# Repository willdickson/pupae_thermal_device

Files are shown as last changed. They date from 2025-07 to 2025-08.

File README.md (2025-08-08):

## pupae_thermal_device  

A temperature controller for thermal experiments with
Drosophila melanogaster pupea. This device consists of two almuminum plates
separated by a narrow channel in which pupae are placed. Each aluminum plate
has a temperature sensor on the upper surface and sits a Peltier thermoelectric
module.  The temperature of the plates is controlled independently using a
feedback (PID) temperature controller implemented on the an Adafruit Feather
RP2350 in combination with the Adafruit DC Motor Featherwing and Sparkfun's
micro STTS22H temperature sensor. The set-points, plate temperatures and
enabled/disable status are displayed on an Adafruit OLED Featherwing. The three
(A, B, C) buttons on the OLED Fetherwing are used to control the plate set-point temperatures 
and to toggle the controller's enabled/disabled state.

## License: 
Creative Commons Attribution 4.0 International CC BY 4.0

## Device Image 

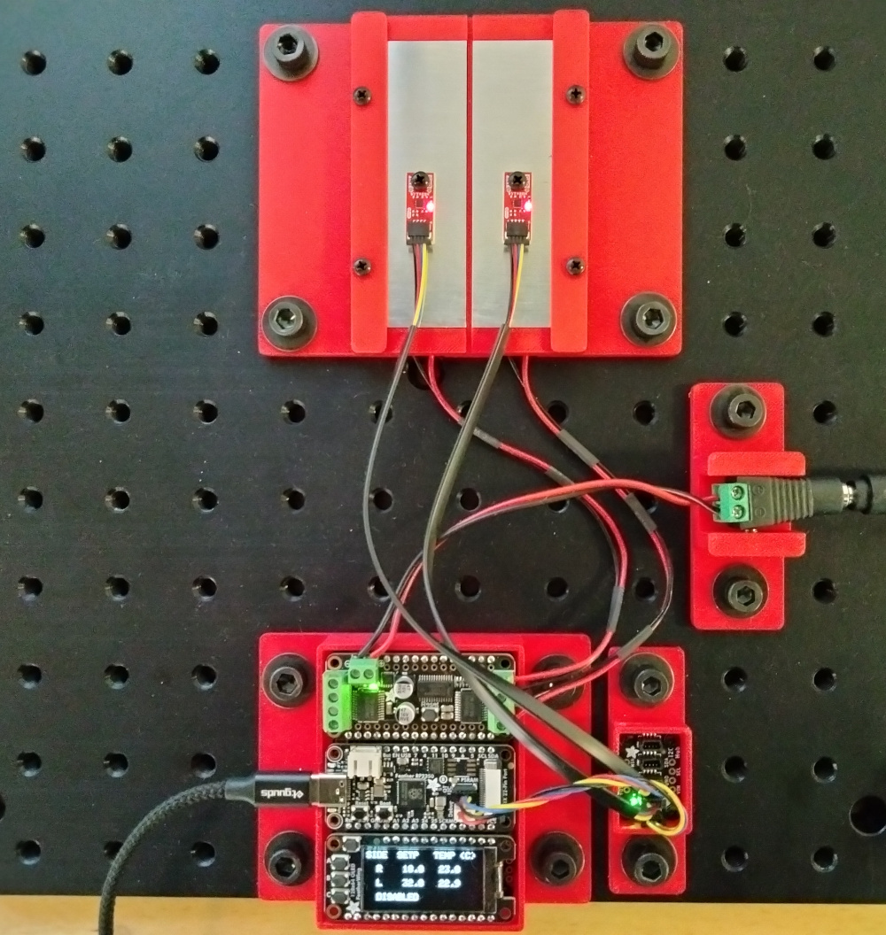
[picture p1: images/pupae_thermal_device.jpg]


## OLED display and control buttons

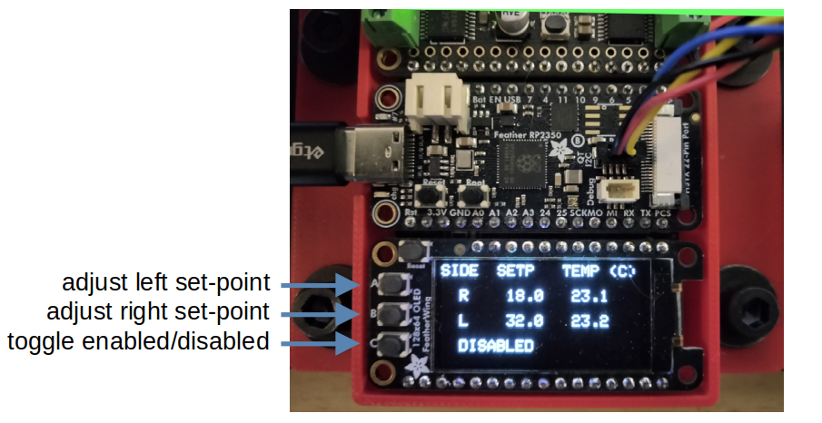
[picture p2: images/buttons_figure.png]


The set-point temperatures for the plates and the temperature controller's
state (enabled/disabled) can be controlled using the A, B and C buttons on the
Adafruit OLED Featherwing.

* A/B buttons control right/left plate set-points.  The A/B buttons are
  stateful and will be either in a state where a button press (or hold)
  increases the value or in a state where the button press (or hold) decreases
  the values.  The state can be changed by a quick double press of the button
  where there is less than 0.5s between the two presses.  Slow button presses -
  greater than 0.5s between presses - will increment (or decrement) the
  set-point one step per press.  Pressing and holding the button will cause the
  values to rapidly increment (or decrement). A quick double press of the
  button will change the direction of the steps. 

* The C button can be used to toggle the temperature controllers
  enabled/disabled state. If the text on the OLED screen next to the C button
  says "enabled" then the temperature controllers are enabled. In this case
  pressing the C button this disable the controllers. If the text on the OLED 
  screen next to the C button says "disabled" then pressing the C button will
  disable the temperature controllers.

## Controller tuning GUI 
A simple GUI tool is also available "pupae_thermal_device_tuner" for tuning the
PID controller gains. The tool live streams the systems values - temperature,
setpoint, error, ierror, derror, power - and enables the user to adjust the
set-points and gains of the controllers.  

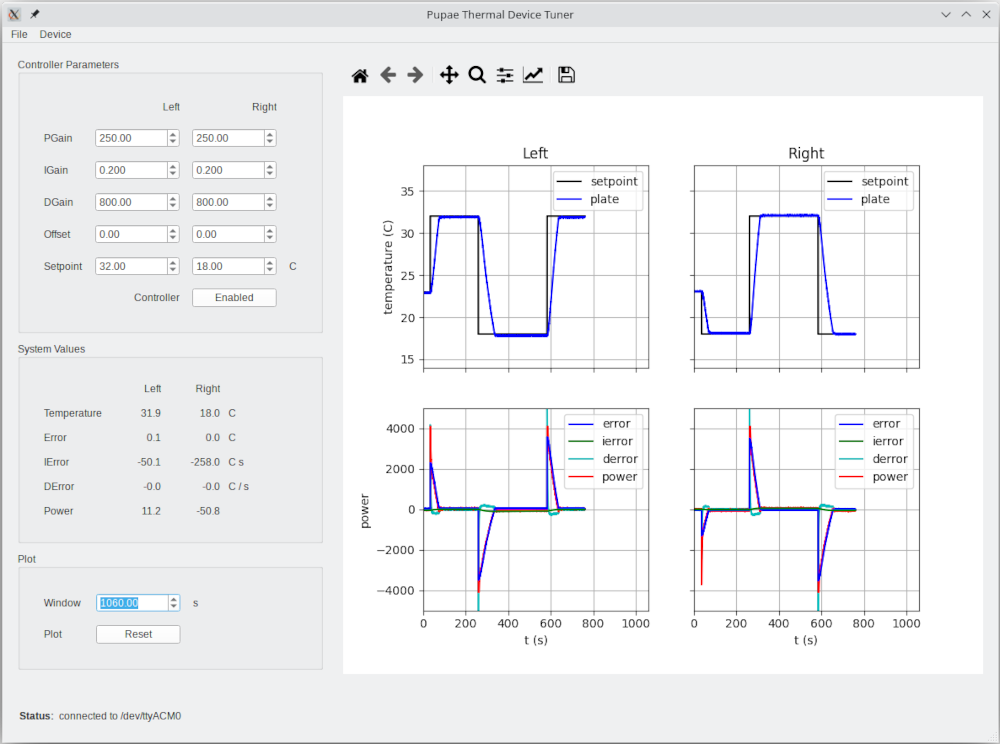
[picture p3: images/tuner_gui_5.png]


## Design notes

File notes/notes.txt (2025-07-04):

Peltier
Laird Thermal Systems, Inc.
Manufacture PN 387005513
https://lairdthermal.com/products/thermoelectric-cooler-modules/peltier-thermal-cycling-pcx-series/387005513

Digikey PN 1487-387005513-ND
https://www.digikey.com/en/products/detail/laird-thermal-systems-inc/387005513/15912562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

Heatsinks
https://www.digikey.com/en/products/detail/fischer-elektronik/SK-521-75-SA/25827986
https://www.digikey.com/en/products/detail/fischer-elektronik/SK-693-75-ME/25828168

Adafruit
DC Motor + Stepper FeatherWing Add-on For All Feather Boards
https://www.adafruit.com/product/2927

Adafruit
Adafruit MLX90640 IR Thermal Camera Breakout - 55 Degree
https://www.adafruit.com/product/4407

Sparkfun
SparkFun Micro Temperature Sensor - STTS22H
https://www.sparkfun.com/sparkfun-micro-temperature-sensor-stts22h-qwiic.html

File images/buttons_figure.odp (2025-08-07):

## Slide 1

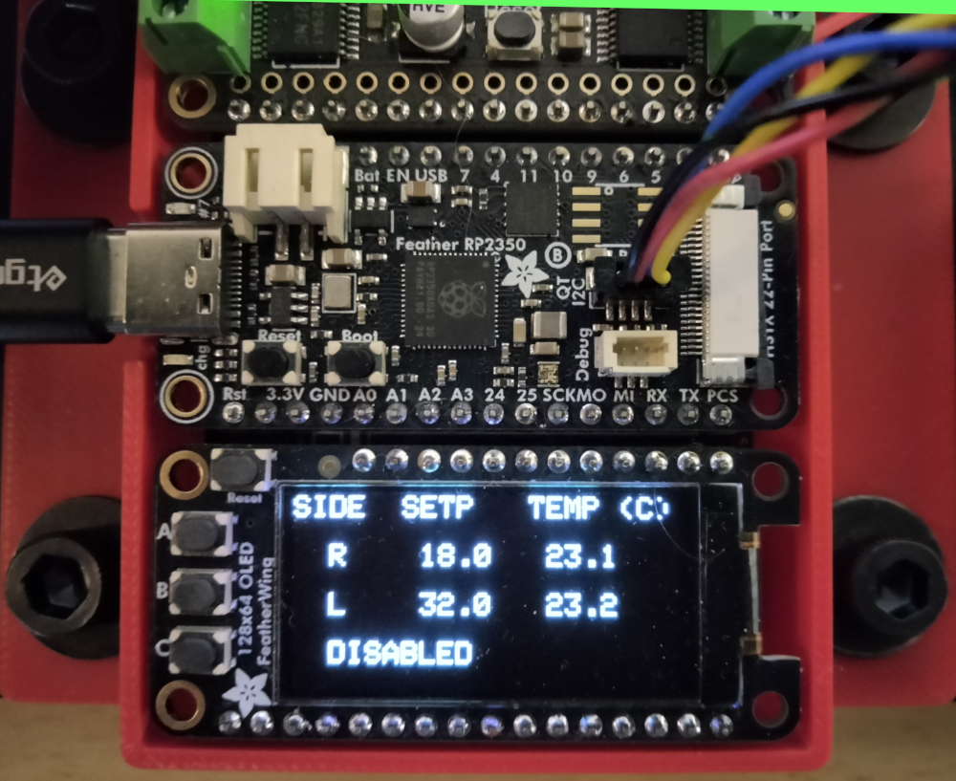
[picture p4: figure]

adjust left set-point

adjust right set-point

toggle enabled/disabled

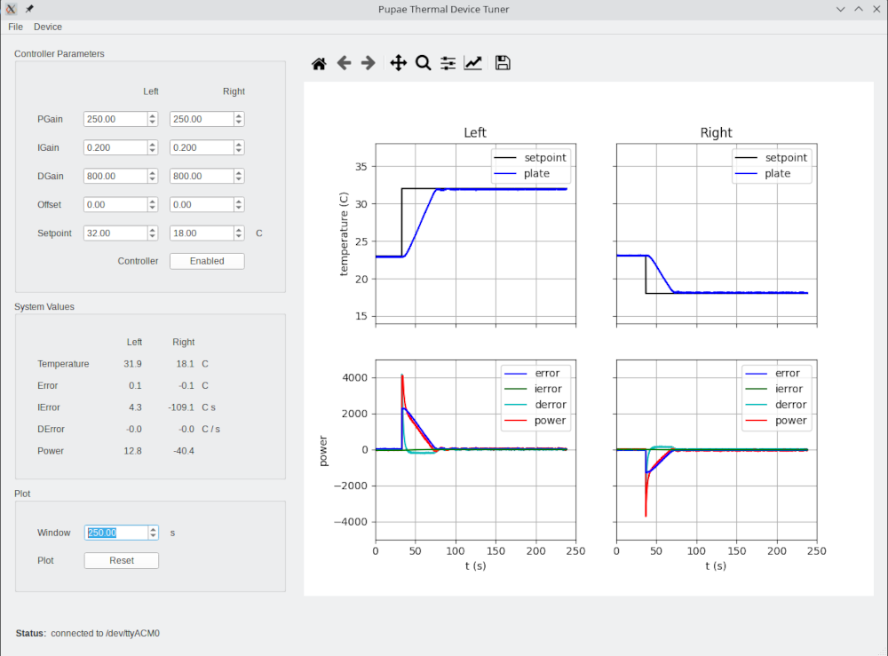
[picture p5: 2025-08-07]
images/tuner_gui_3.png

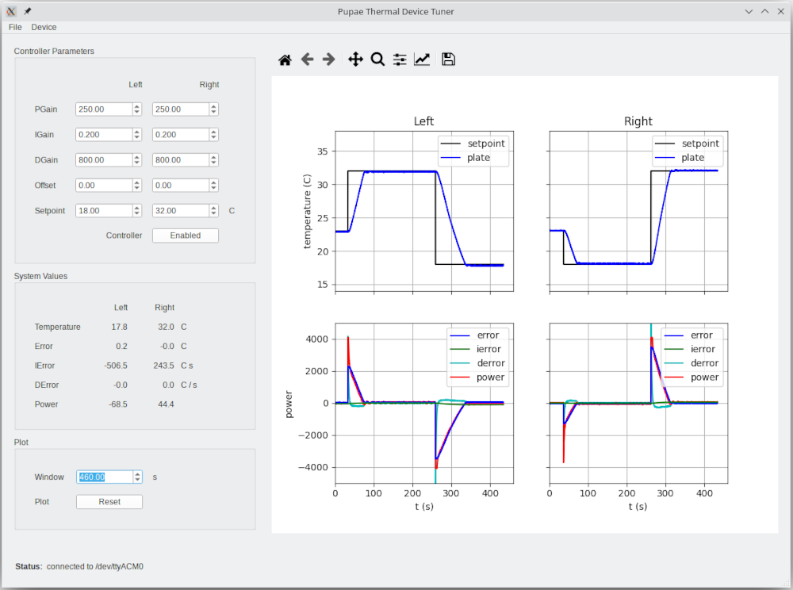
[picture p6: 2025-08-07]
images/tuner_gui_4.png

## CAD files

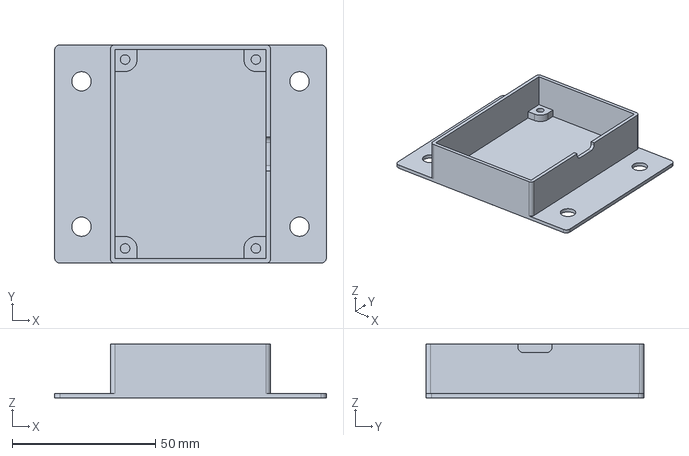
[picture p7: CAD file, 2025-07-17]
mechanics/feather_tripler_enclosure.FCStd
95.1 x 76.3 x 18.8 mm

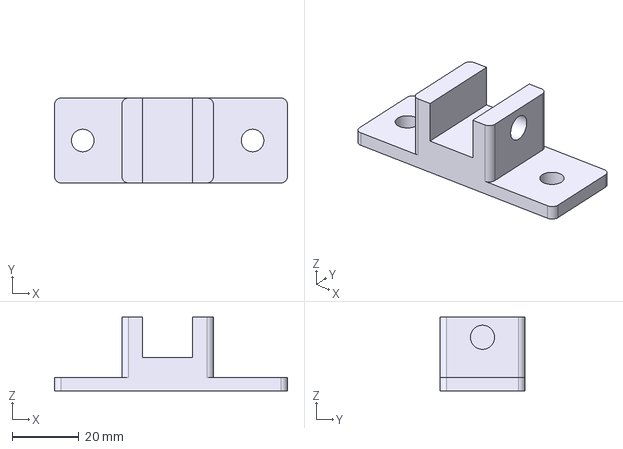
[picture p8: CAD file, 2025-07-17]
mechanics/step/power_connector_mount_v0p1_r1.step
69.7 x 25.4 x 22.0 mm

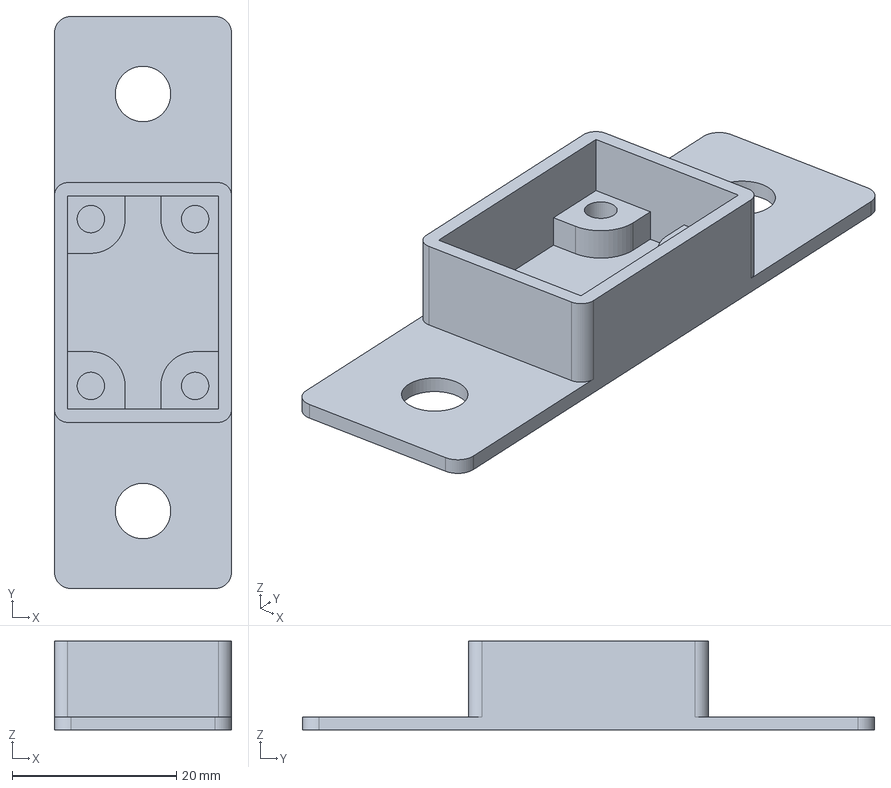
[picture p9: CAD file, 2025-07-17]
mechanics/qt_5p_hub_enclosure.FCStd
21.6 x 69.7 x 10.8 mm

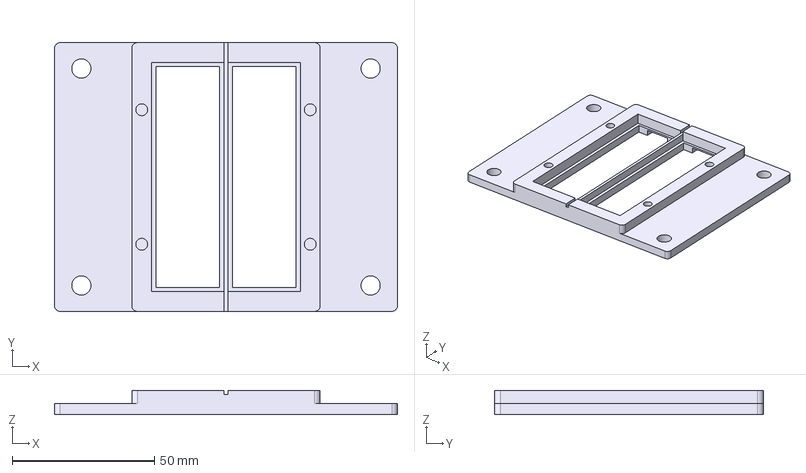
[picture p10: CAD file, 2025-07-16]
mechanics/step/pupae_thermal_device_frame_v0p2_r1.step
120.5 x 94.4 x 8.60 mm

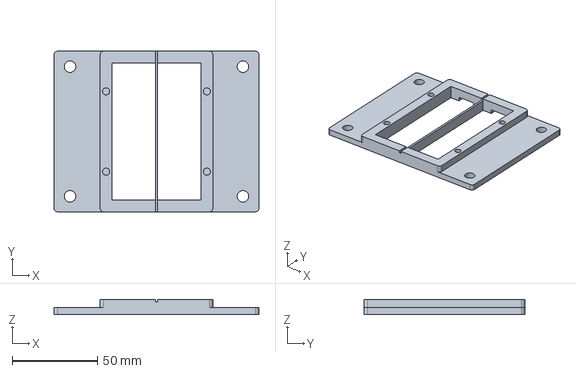
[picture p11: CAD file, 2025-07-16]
mechanics/pupae_thermal_device_frame_v2.FCStd
120.5 x 94.4 x 8.60 mm

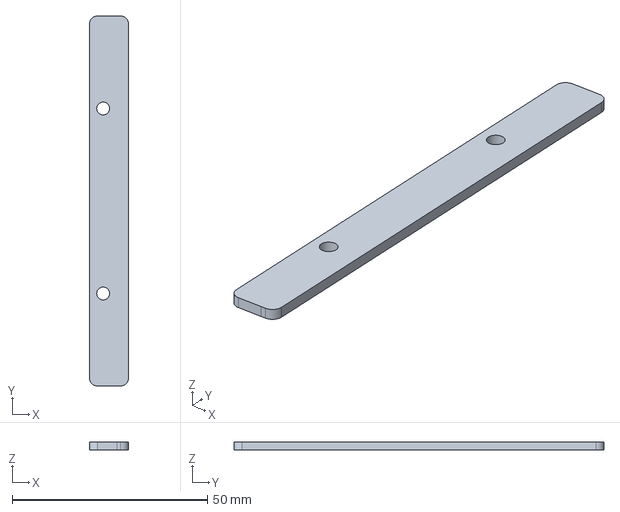
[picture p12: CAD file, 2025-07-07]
mechanics/pupae_thermal_device_cover.FCStd
10.0 x 94.8 x 2.00 mm

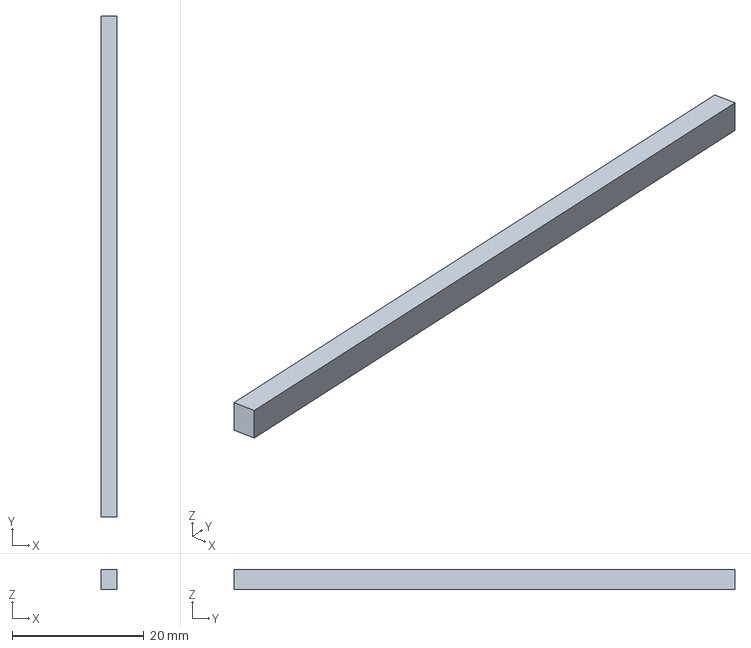
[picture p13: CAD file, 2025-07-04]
mechanics/peltier_side_plate.FCStd
2.50 x 76.0 x 3.10 mm

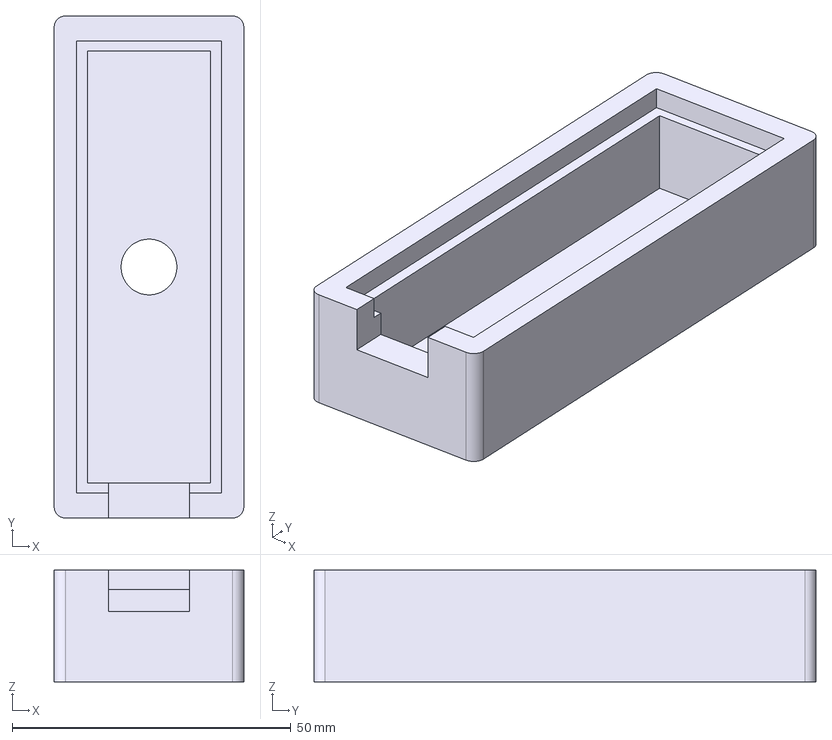
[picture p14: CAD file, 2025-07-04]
mechanics/step/peltier_stack_jig.step
34.0 x 90.0 x 20.0 mm

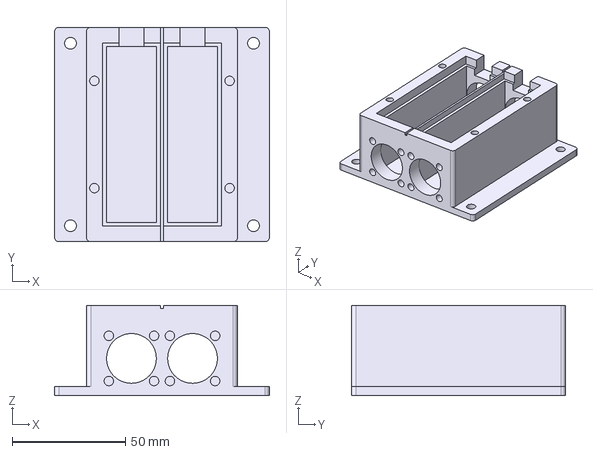
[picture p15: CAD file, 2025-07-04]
mechanics/step/pupae_thermal_device_frame_v0p1_r2.step
95.1 x 94.8 x 40.0 mm

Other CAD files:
mechanics/step/qt_5p_hub_enclosure_v0p1_r1.step
mechanics/power_connector_mount.FCStd
mechanics/step/pupae_thermal_device_frame_v0p2_r2.step
mechanics/step/feather_tripler_enclosure_v0p1_r1.step
mechanics/step/pupae_thermal_device_cover_v0p1_r1.step
mechanics/step/peltier_side_plate_v0p1_r1.step
mechanics/step/pupae_thermal_device_frame_v0p1_r1.step
mechanics/step/pupae_thermal_device_frame_v0p1_r3.step
mechanics/pupae_thermal_device_frame_v1.FCStd
mechanics/peltier_stack_jig.FCStd

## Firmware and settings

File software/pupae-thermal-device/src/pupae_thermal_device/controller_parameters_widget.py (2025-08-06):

from PySide6 import QtCore
from PySide6 import QtWidgets
from .ui_controller_parameters_widget import Ui_ControllerParametersWidget
from .pupae_thermal_device import PupaeThermalDevice


class ControllerParametersWidget(QtWidgets.QWidget, Ui_ControllerParametersWidget):

    TEXT_ENABLED = 'Enabled'
    TEXT_DISABLED = 'Disabled'

    sig_setpoint_left_changed = QtCore.Signal(float)
    sig_setpoint_right_changed = QtCore.Signal(float)

    def __init__(self, parent=None):
        super().__init__(parent=parent)
        self.setupUi(self)
        self.initialize()
        self.setup_connections()
        self.device = None

    def initialize(self):
        self.set_enable_disable_pushbutton_text(False)

    def connect_device_open_close_slots(self, connection_dialog):
        connection_dialog.sig_opened.connect(self.slot_device_opened)
        connection_dialog.sig_closed.connect(self.slot_device_closed)

    def setup_connections(self):
        self.pgain_left_dblspinbox.valueChanged.connect(self.on_pgain_left_value_changed)
        self.pgain_right_dblspinbox.valueChanged.connect(self.on_pgain_right_value_changed)
        self.igain_left_dblspinbox.valueChanged.connect(self.on_igain_left_value_changed)
        self.igain_right_dblspinbox.valueChanged.connect(self.on_igain_right_value_changed)
        self.dgain_left_dblspinbox.valueChanged.connect(self.on_dgain_left_value_changed)
        self.dgain_right_dblspinbox.valueChanged.connect(self.on_dgain_right_value_changed)
        self.offset_left_dblspinbox.valueChanged.connect(self.on_offset_left_value_changed)
        self.offset_right_dblspinbox.valueChanged.connect(self.on_offset_right_value_changed)
        self.setpoint_left_dblspinbox.valueChanged.connect(self.on_setpoint_left_value_changed)
        self.setpoint_right_dblspinbox.valueChanged.connect(self.on_setpoint_right_value_changed)
        self.enable_disable_pushbutton.clicked.connect(self.on_enable_disable_pushbutton_clicked)

    def set_enable_disable_pushbutton_text(self, ctrl_enabled):
        if ctrl_enabled:
            self.enable_disable_pushbutton.setText(self.TEXT_ENABLED)
        else:
            self.enable_disable_pushbutton.setText(self.TEXT_DISABLED)

    @QtCore.Slot(PupaeThermalDevice,str)
    def slot_device_opened(self, device, port_name):
        self.device = device
        values = self.device.get_all()
        self.pgain_right, self.pgain_left = values['ctrl_pgain']
        self.igain_right, self.igain_left = values['ctrl_igain']
        self.dgain_right, self.dgain_left = values['ctrl_dgain']
        self.offset_right, self.offset_left = values['ctrl_offset']
        self.setpoint_right, self.setpoint_left = values['ctrl_setpoint']
        self.set_enable_disable_pushbutton_text(values['ctrl_enabled'])

    @QtCore.Slot()
    def slot_device_closed(self):
        self.device = None

    @property
    def pgain_left(self):
        return self.pgain_left_dblspinbox.value()

    @pgain_left.setter
    def pgain_left(self, value):
        self.pgain_left_dblspinbox.setValue(value)

    @property
    def pgain_right(self):
        return self.pgain_right_dblspinbox.value()

    @pgain_right.setter
    def pgain_right(self, value):
        self.pgain_right_dblspinbox.setValue(value)

    @property
    def igain_left(self):
        return self.igain_left_dblspinbox.value()

    @igain_left.setter
    def igain_left(self, value):
        self.igain_left_dblspinbox.setValue(value)

    @property
    def igain_right(self):
        return self.igain_right_dblspinbox.value()

    @igain_right.setter
    def igain_right(self, value):
        self.igain_right_dblspinbox.setValue(value)

    @property
    def dgain_left(self):
        return self.dgain_left_dblspinbox.value()

    @dgain_left.setter
    def dgain_left(self, value):
        self.dgain_left_dblspinbox.setValue(value)

    @property
    def dgain_right(self):
        return self.dgain_right_dblspinbox.value()

    @dgain_right.setter
    def dgain_right(self, value):
        self.dgain_right_dblspinbox.setValue(value)

    @property
    def offset_left(self):
        return self.offset_left_dblspinbox.value()

    @offset_left.setter
    def offset_left(self, value):
        self.offset_left_dblspinbox.setValue(value)

    @property
    def offset_right(self):
        return self.offset_right_dblspinbox.value()

    @offset_right.setter
    def offset_right(self, value):
        self.offset_right_dblspinbox.setValue(value)

    @property
    def setpoint_left(self):
        return self.setpoint_left_dblspinbox.value()

    @setpoint_left.setter
    def setpoint_left(self, value):
        if not self.setpoint_left_dblspinbox.hasFocus():
            self.setpoint_left_dblspinbox.setValue(value)

    @property
    def setpoint_right(self):
        return self.setpoint_right_dblspinbox.value()
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

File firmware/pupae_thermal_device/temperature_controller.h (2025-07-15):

#ifndef TEMPERATURE_CONTROLLER_H
#define TEMPERATURE_CONTROLLER_H
#include "constants.h"
#include "Adafruit_MotorShield.h"
#include "SparkFun_STTS22H.h"
#include "peltier_drive.h"



class TemperatureController {

    public:
        TemperatureController();
        void initialize(uint8_t sensor_address, Adafruit_DCMotor *motor);

        void update();
        void update(float ambient);

        float temperature();

        uint8_t sensor_address();

        bool enabled();
        void set_enabled(bool value);

        float setpoint();
        void set_setpoint(float value); 

        float gain();
        void set_gain(float value);

        float ff_slope();
        void set_ff_slope(float value);

        float ambient();
        void set_ambient(float value);

        static constexpr uint32_t SENSOR_SETUP_DT = 100;
        static constexpr float DEFAULT_SETPOINT = 22.0;
        static constexpr float DEFAULT_GAIN = 1.0;
        static constexpr float DEFAULT_FF_SLOPE = 0.0;
        static constexpr float DEFAULT_AMBIENT = 22.0;


    protected:
        SparkFun_STTS22H sensor_;
        PeltierDrive peltier_drive_ = PeltierDrive();

        bool enabled_ = false;
        uint8_t sensor_address_ = 0;
        float setpoint_ = DEFAULT_SETPOINT;
        float gain_ = DEFAULT_GAIN;
        float ff_slope_ = DEFAULT_FF_SLOPE;
        float ambient_ = DEFAULT_AMBIENT;
        float temperature_ = DEFAULT_AMBIENT;

};

#endif

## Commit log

2025-07-04 Project creation.
    [feather_tripler_enclosure.FCStd, peltier_side_plate.FCStd, peltier_side_plate_v0p1_r1.step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]
2025-07-07 Added design for cover plate.
    [pupae_thermal_device_cover.FCStd, pupae_thermal_device_cover_v0p1_r1.step, pupae_thermal_device_frame.FCStd]
2025-07-08 Started firmware tests. Note, there is i2c collision between
    display and STTS22H temperature sensors.
2025-07-15 Worked on temperature controller.
2025-07-16 Worked on firmware and mechanics.
    Modified temperature controller so that it is now a PI controller.
    Modified frame to work with breadboard as heatsink. Finished initial
    enclosure design for feather tripler.
    [feather_tripler_enclosure.FCStd, feather_tripler_enclosure_v0p1_r1.step, pupae_thermal_device_frame_v0p2_r1.step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]
2025-07-17 Added designs for QT hub enclosure and power connector mount.
    [feather_tripler_enclosure.FCStd, power_connector_mount.FCStd, power_connector_mount_v0p1_r1.step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]
2025-07-18 Added display output and started connecting push buttons.
2025-07-19 Worked on button interface for chaning set points.
2025-08-05 Added plots for setpoint, temperature, error, ierror and power.
    [mplcanvas.py, plot_settings_widget.py, pupae_thermal_device_tuner.py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]
2025-08-06 Added derivative term to temperature controller. Worked on tuning.
2025-08-07 Fixed GUI units issue. Modified default gains. Added images/readme.
    [ui_system_values_widget.py]
